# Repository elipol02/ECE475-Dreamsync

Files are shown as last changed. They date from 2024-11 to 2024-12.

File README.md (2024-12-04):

# Dreamsync

## Project Overview
Our product Dreamsync is designed to enhance health monitoring by integrating sensors that track various metrics related to sleep quality and environmental conditions. Data collected from the sensors are transmitted to a companion mobile application via Bluetooth for analysis and visualization. This will make it easier for our users to track their sleeping patterns.

### Features
- **Sleep Movement Monitoring**: Tracks body movements during sleep using an MPU6050 accelerometer and gyroscope.
- **Heart Rate Monitoring**: Continuously monitors heart rate using a photoplethysmography (PPG) sensor.
- **Environmental Light Exposure**: Measures light levels in the sleep environment using light sensors.
- **Ambient Temperature Monitoring**: Tracks the ambient temperature using a DS18B20 temperature sensor.
- **Battery Monitoring**: Measures battery voltage, percentage, and charging status.
- **Bluetooth Connectivity**: Transmits real-time sensor data to a companion app via BLE (Bluetooth Low Energy).

---

## Components and Dependencies

### Hardware Components
- **MPU6050**: Accelerometer and gyroscope for motion tracking.
- **DS18B20**: Temperature sensor.
- **PPG Sensor**: For heart rate monitoring.
- **Light Sensors**: Measures light levels (connected to analog pins A0 and A1).
- **nRF52840 Feather**: For Bluetooth communication.
- **LED**: Visual feedback for heart rate peaks.

### Software Libraries
- **Wire**: I2C communication with MPU6050.
- **OneWire**: Communication protocol for DS18B20.
- **DallasTemperature**: Interface for DS18B20 temperature sensor.
- **Adafruit Bluefruit**: Bluetooth communication.
- **Adafruit LittleFS**: Internal file system for configuration storage.

---

## Setup Instructions

### Hardware Setup
1. Connect the **MPU6050** to the I2C pins (SDA, SCL).
2. Attach the **DS18B20** sensor to `TEMP_SENSOR_PIN` (A2).
3. Connect **PPG Sensor** to `HEART_RATE_PIN` (A3).
4. Connect light sensors to `LIGHT_SENSOR_1` (A0) and `LIGHT_SENSOR_2` (A1).
5. Connect the LED to `LED_PIN` (3).

### Software Setup
1. You'll need to install the libraries we listed above.
2. Upload the firmware code provided to your nRF52840 development board via Arduino IDE.

### Mobile Application
1. Ensure the Bluetooth is enabled on your mobile device.
2. Pair with the "SleepMask" device via BLE.
3. Use the companion app to visualize and analyze the collected data.

---

## Code Highlights

### Key Functions
- **`initializeMPU6050()`**: Initializes the MPU6050 for motion tracking.
- **`readLightAndTemp()`**: Reads ambient light and temperature values.
- **`readHeartRateSensor()`**: Reads and processes heart rate data.
- **`calculateBPM()`**: Calculates beats per minute (BPM) based on PPG data.
- **`sendEnvironmentalData()`**: Sends light and temperature data over BLE.
- **`checkBattery()`**: Monitors battery voltage and percentage.
- **`startAdv()`**: Configures and starts BLE advertising.

### BLE Services
- **Device Information Service**: Provides metadata about the device.
- **UART Service**: Transmits sensor data to the mobile app.
- **Battery Service**: Sends battery status updates.

---

## Sensor Data Format

The sensor data is transmitted to the companion app in the following format:
1. **Environmental Data**: `E,light1,light2,temperature`
2. **Heart Rate Data**: `H,heartRate`
3. **Motion Data**: `M,accelX,accelY,accelZ,gyroX,gyroY,gyroZ,pitch,roll,motionIntensity`
4. **Battery Data**: `B,batteryVoltage,batteryPercent,isCharging`

---

## Contributors

Chukwuemeka Mordi, Chu-en Chang, Elijah Pollack, Kinner Parikh

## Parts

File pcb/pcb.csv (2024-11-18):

Source: | C:\Users\Eli\Documents\GitHub\ece475group7\pcb\pcb.kicad_sch
Date: | 11/16/2024 10:39
Tool: | Eeschema 7.0.10
Generator: | C:\Program Files\KiCad\7.0\bin\scripting\plugins/bom_csv_grouped_by_value_with_fp.py
Component Count: | 109
Ref | Qnty | Value | Cmp name | Footprint | Description | Vendor | DNP
C1 | 1 | 0.01uF | GRM155R71C103KA01D | Library:CAPC2012X95N
C2, C3, C4, C15, C16, C17, C18, C20, C21, C24, C25, C27, C28, C31, C34, C36, C38, C40 | 18 | 0.1uF | CL05B104KP5NNNC | Library:CAPC2012X88N
C5, C6 | 2 | 22pF | CAP_CERAMIC0603_NO | Library:CAPC220145_88N_KEM
C7, C8, C12, C13, C14 | 5 | 10uF | CAP_CERAMIC0805-NOOUTLINE | Library:CAPC2012X88N
C9, C10, C11 | 3 | 0.1uF | CAP_CERAMIC0603_NO | Library:CAPC2012X88N
C19, C26, C35, C37 | 4 | 10uF | CL21A106KOQNNNG | Library:CAPC2012X88N
C22, C29, C32, C39, C41 | 5 | 2.2nF | Capacitor | Library:CAP_CL21_SAM
C23, C30, C33, C42 | 4 | 1nF | Capacitor | Library:CAP_0805J_AVX
D1 | 1 | RED | LED0805_NOOUTLINE | Library:WL-SMCW_0805
D2 | 1 | MBR120 | DIODE-SCHOTTKYSOD-123 | Library:SDO_SOD-123FL498_OSI
D3 | 1 | ORANGE | LED0805_NOOUTLINE | Library:WL-SMCW_0805
D4 | 1 | BLUE | LED0805_NOOUTLINE | Library:WL-SMCW_0805
D5 | 1 | 2659 | 2659 | Library:2659
IC1 | 1 | GD25Q16 | SPIFLASH_8PINUX | Library:SOIC127P600X175-8N
J1 | 1 | 10118194-0001LF | 10118194-0001LF | Library:AMPHENOL_10118194-0001LF
J2 | 1 | 533980271 | 533980271 | Library:MOLEX_0533980271
MDBT1 | 1 | MDBT50 | MDBT50 | Library:MDBT50Q-U
Q3 | 1 | DMG2305 | MOSFET-P | Library:SOT91P240X110-3N_DMG2305UX-7
R1, R2, R3, R14, R19, R32 | 6 | 22 | CRCW251220R0FKEG | Library:RESC2012X60N
R4, R5, R8, R11, R15, R20, R22, R25, R26, R27, R33 | 11 | 4.7K | Resistor | Library:RESC2012X60N
R6, R9, R10 | 3 | 1K | RESISTOR_0603_NOOUT | Library:RESC2012X60N
R7, R24, R36, R37, R38 | 5 | 100K | Resistor | Library:RESC2012X60N
R12, R13, R18, R31 | 4 | 2.2K | Resistor | Library:RESC2012X60N
R16, R17, R21, R28, R29, R30, R34, R35 | 8 | 3.74K | Resistor | Library:RESC2012X60N
R23 | 1 | 30K | ERA2AEB303X | Library:RESC2012X65N
SW1, SW2 | 2 | KMR223G LFG | KMR223G_LFG | Library:KMR2_G_CNK
U1 | 1 | MPU-6050 | MPU-6050 | Sensor_Motion:InvenSense_QFN-24_4x4mm_P0.5mm | InvenSense 6-Axis Motion Sensor, Gyroscope, Accelerometer, I2C
U2 | 1 | DS18B20 | DS18B20 | Package_TO_SOT_THT:TO-92_Inline | Programmable Resolution 1-Wire Digital Thermometer TO-92
U4, U5, U10, U12 | 4 | INA333xxDGK | INA333xxDGK | Library:SOP65P490X110-8N | Zero Drift, Micropower Instrumentation Amplifier G = 1 + 100kOhm/Rg, VSSOP-8
U6 | 1 | CS5523-ASZ | CS5523-ASZ | Library:CIR-SSOP-24
U7 | 1 | AP2112(3.3V) | VREG_SOT23-5 | Library:SOT_RG1_DIO
U8 | 1 | MCP73831T-2ACI/OT | MCP73831/2 | Library:SOT-23-5_MC_MCH
U9, U11, U13, U15 | 4 | LM358DT | LM358DT | Library:SOIC127P600X175-8N
U20 | 1 | MCP6001-OT | MCP6001-OT | Package_TO_SOT_SMD:SOT-23-5 | 1MHz, Low-Power Op Amp, SOT-23-5
X1 | 1 | 2x5 0.05" | JTAG-CORTEXBOXPOSTS | Library:2X05_1.27MM_BOX_POSTS
Y1 | 1 | 32.768 | XTAL-3.2X1.5 | Library:XTAL_SC32S-7PF20PPM_EPS
 | 108

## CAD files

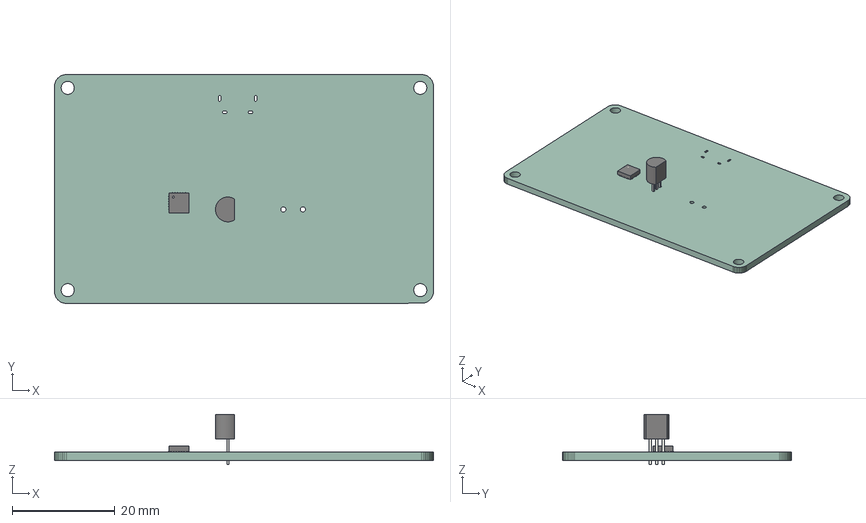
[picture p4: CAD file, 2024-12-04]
pcb/pcb.step
73.7 x 44.5 x 9.80 mm
TO-92_Inline_Narrow
QFN_24_1EP_4x4mm_P05mm_EP27x26mm
_autosave-pcb PCB

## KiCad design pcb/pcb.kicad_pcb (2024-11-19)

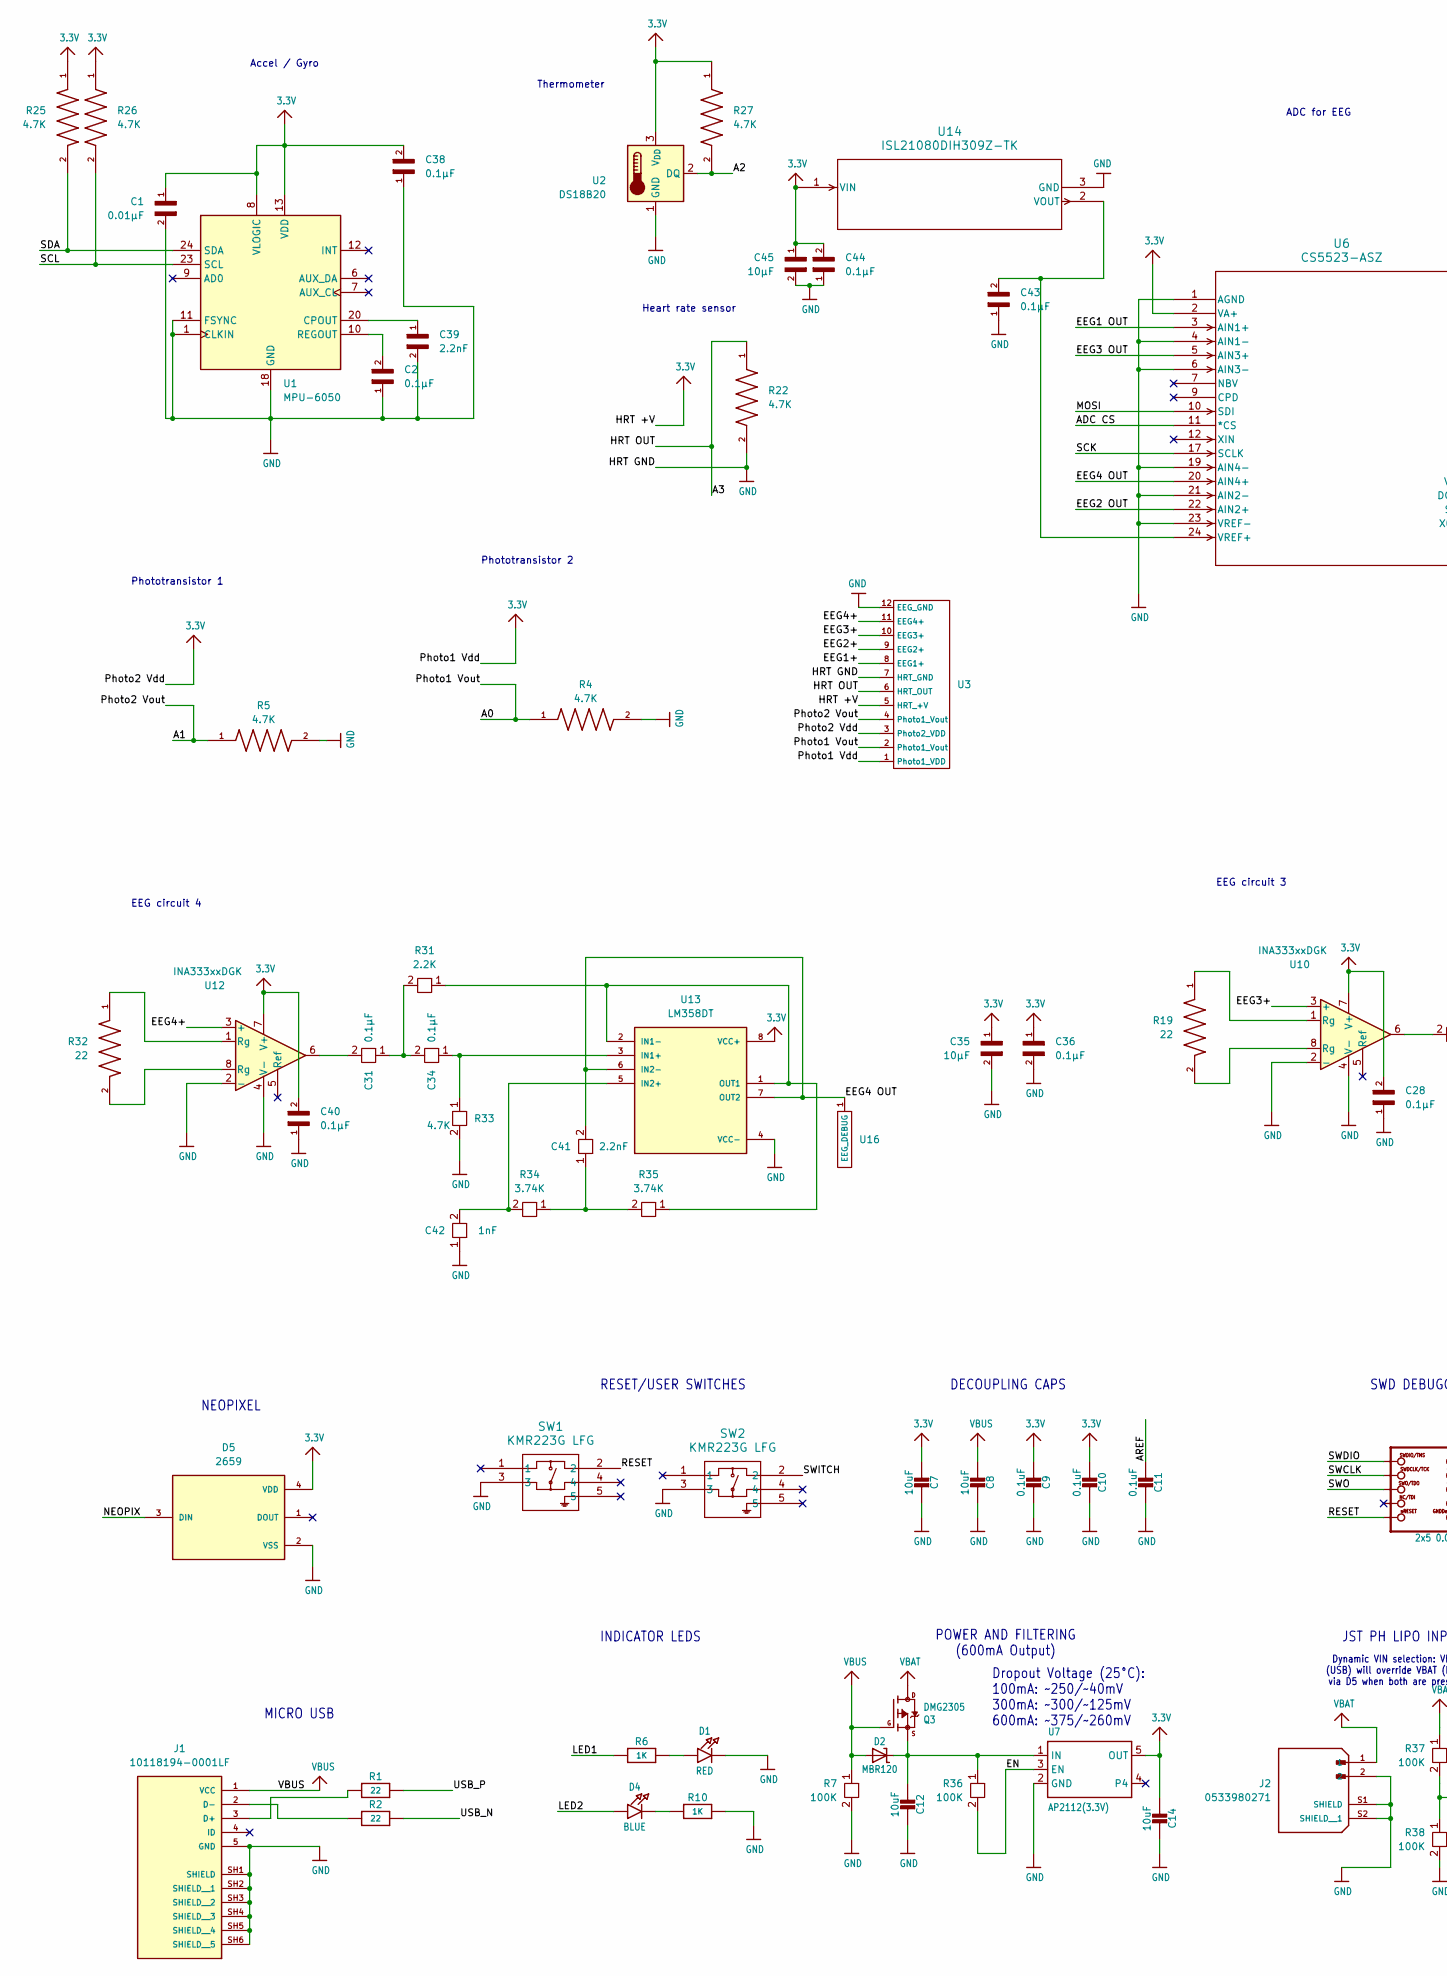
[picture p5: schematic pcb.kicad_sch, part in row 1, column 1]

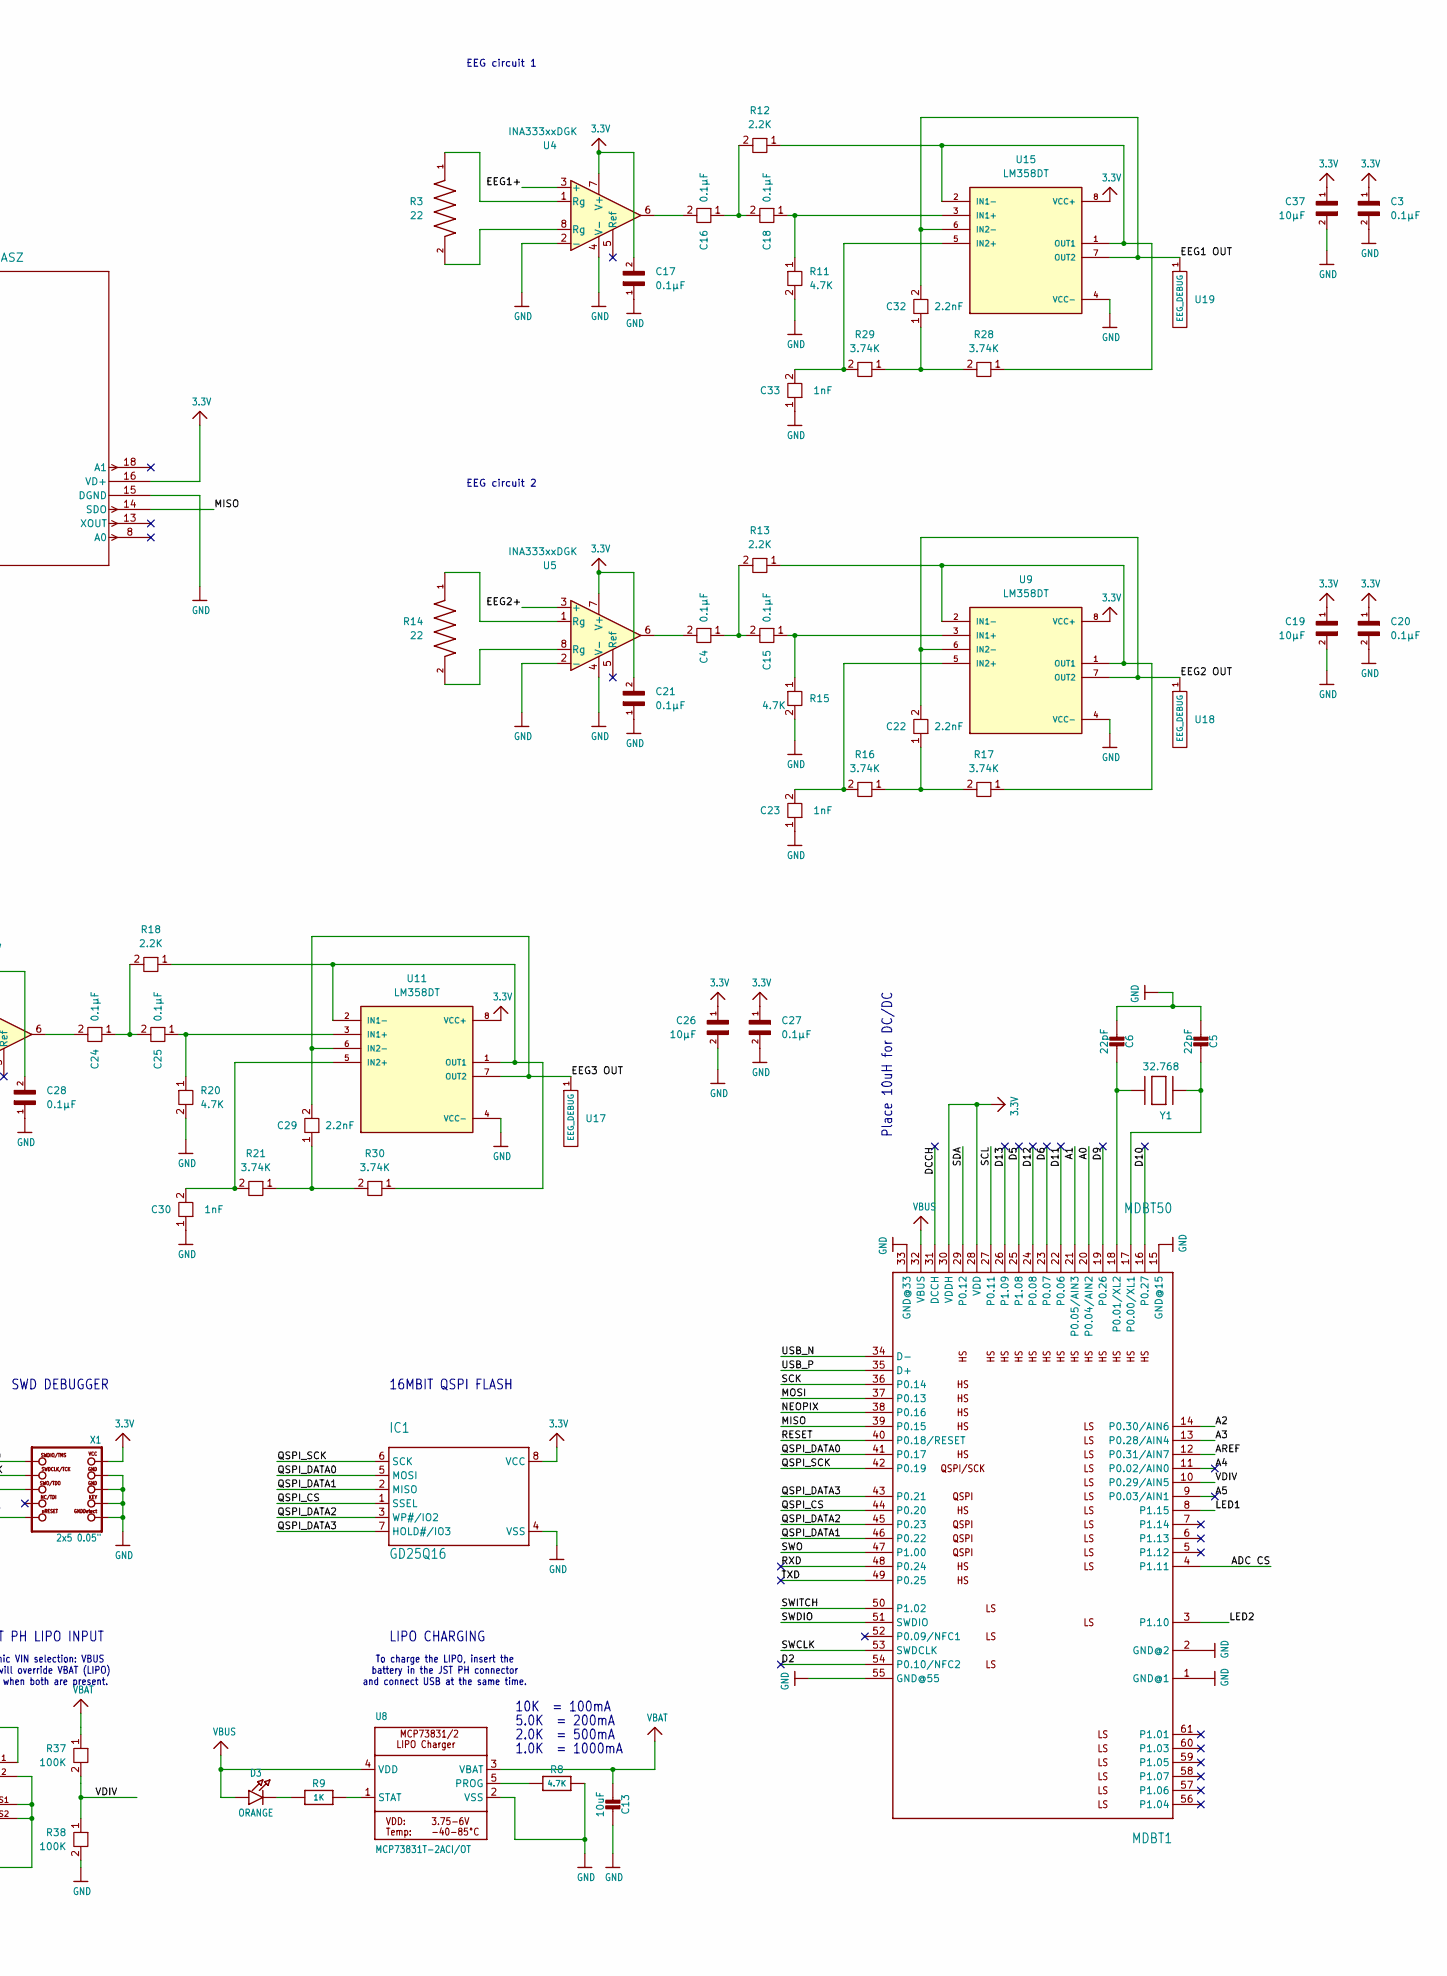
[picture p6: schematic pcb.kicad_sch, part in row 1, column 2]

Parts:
C1: 0.01μF; CAPC2012X95N
C2, C3, C4, C15, C16, C17, C18, C20, C21, C24, C25, C27, C28, C31, C34, C36, C38, C40, C43, C44: 0.1μF; CAPC2012X88N
C5, C6: 22pF; CAPC220145_88N_KEM
C7, C8, C12, C13, C14: 10uF; CAPC2012X88N
C9, C10, C11: 0.1uF; CAPC2012X88N
C19, C26, C35, C37, C45: 10μF; CAPC2012X88N
C22, C29, C32, C39, C41: 2.2nF; CAP_CL21_SAM
C23, C30, C33, C42: 1nF; CAP_0805J_AVX
D1: RED; WL-SMCW_0805
D2: MBR120; SDO_SOD-123FL498_OSI
D3: ORANGE; WL-SMCW_0805
D4: BLUE; WL-SMCW_0805
D5: 2659; PARTREV 01
IC1: GD25Q16; SOIC127P600X175-8N
J1: 10118194-0001LF; AMPHENOL_10118194-0001LF; PARTREV D
J2: 0533980271; MOLEX_0533980271; PARTREV A
MDBT1: MDBT50; MDBT50Q-U
Q3: DMG2305; SOT91P240X110-3N_DMG2305UX-7
R1, R2, R3, R14, R19, R32: 22; RESC2012X60N
R4, R5, R22, R25, R26, R27: 4.7K; RESC2012X60N; DigiKey_Part_Number 311-4.7KJRTR-ND
R6, R9, R10: 1K; RESC2012X60N
R7, R36, R37, R38: 100K; RESC2012X60N
R8, R11, R15, R20, R33: 4.7K; RESC2012X60N
R12, R13, R18, R31: 2.2K; RESC2012X60N
R16, R17, R21, R28, R29, R30, R34, R35: 3.74K; RESC2012X60N
SW1, SW2: KMR223G LFG; KMR2_G_CNK
U1: MPU-6050; InvenSense_QFN-24_4x4mm_P0.5mm
U2: DS18B20; TO-92_Inline
U3: Sensors
U4, U5, U10, U12: INA333xxDGK; SOP65P490X110-8N
U6: CS5523-ASZ; CIR-SSOP-24
U7: AP2112(3.3V); SOT_RG1_DIO
U8: MCP73831T-2ACI/OT; SOT-23-5_MC_MCH
U9, U11, U13, U15: LM358DT; SOIC127P600X175-8N
U14: ISL21080DIH309Z-TK; P3_064_INR
U16, U17, U18, U19: EEG_DEBUG
X1: 2x5 0.05"; 2X05_1.27MM_BOX_POSTS
Y1: 32.768; XTAL_SC32S-7PF20PPM_EPS

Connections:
3.3V: C1.1, C3.1, C7.2, C9.2, C10.2, C14.2, C17.2, C19.1, C20.1, C21.2, C26.1, C27.1, C28.2, C35.1, C36.1, C37.1, C38.2, C40.2, C44.2, C45.1, D5.4 (VDD), IC1.8 (VCC), MDBT1.28 (VDD), MDBT1.30 (VDDH), R25.1, R26.1, R27.1, U1.8 (VLOGIC), U1.13 (VDD), U2.3 (V_{DD}), U3.1 (Photo1_VDD), U3.3 (Photo2_VDD), U3.5 (HRT_+V), U4.7 (V+), U5.7 (V+), U6.2 (VA+), U6.16 (VD+), U7.5 (OUT), U9.8 (VCC+), U10.7 (V+), U11.8 (VCC+), U12.7 (V+), U13.8 (VCC+), U14.1 (VIN), U15.8 (VCC+), X1.1 (VCC)
/A0: MDBT1.20 (P0.04/AIN2), R4.1, U3.2 (Photo1_Vout)
/A1: MDBT1.21 (P0.05/AIN3), R5.1, U3.4 (Photo1_Vout)
/A2: MDBT1.14 (P0.30/AIN6), R27.2, U2.2 (DQ)
/A3: MDBT1.13 (P0.28/AIN4), R22.1, U3.6 (HRT_OUT)
/A4: MDBT1.11 (P0.02/AIN0)
/A5: MDBT1.9 (P0.03/AIN1)
/ADC CS: MDBT1.4 (P1.11), U6.11 (*CS)
/AREF: C11.2, MDBT1.12 (P0.31/AIN7)
/D2: MDBT1.54 (P0.10/NFC2)
/D5: MDBT1.25 (P1.08)
/D6: MDBT1.23 (P0.07)
/D9: MDBT1.19 (P0.26)
/D10: MDBT1.16 (P0.27)
/D11: MDBT1.22 (P0.06)
/D12: MDBT1.24 (P0.08)
/D13: MDBT1.26 (P1.09)
/DCCH: MDBT1.31 (DCCH)
/EEG1 OUT: C32.2, U6.3 (AIN1+), U15.6 (IN2-), U15.7 (OUT2), U19.1 (EEG_DEBUG)
/EEG1+: U3.8 (EEG1+), U4.3 (+)
/EEG2 OUT: C22.2, U6.22 (AIN2+), U9.6 (IN2-), U9.7 (OUT2), U18.1 (EEG_DEBUG)
/EEG2+: U3.9 (EEG2+), U5.3 (+)
/EEG3 OUT: C29.2, U6.5 (AIN3+), U11.6 (IN2-), U11.7 (OUT2), U17.1 (EEG_DEBUG)
/EEG3+: U3.10 (EEG3+), U10.3 (+)
/EEG4 OUT: C41.2, U6.20 (AIN4+), U13.6 (IN2-), U13.7 (OUT2), U16.1 (EEG_DEBUG)
/EEG4+: U3.11 (EEG4+), U12.3 (+)
/EN: R36.2, U7.3 (EN)
/LED1: MDBT1.8 (P1.15), R6.1
/LED2: D4.A, MDBT1.3 (P1.10)
/MISO: MDBT1.39 (P0.15), U6.14 (SDO)
/MOSI: MDBT1.37 (P0.13), U6.10 (SDI)
/NEOPIX: D5.3 (DIN), MDBT1.38 (P0.16)
/QSPI_CS: IC1.1 (SSEL), MDBT1.44 (P0.20)
/QSPI_DATA0: IC1.5 (MOSI), MDBT1.41 (P0.17)
/QSPI_DATA1: IC1.2 (MISO), MDBT1.46 (P0.22)
/QSPI_DATA2: IC1.3 (WP#/IO2), MDBT1.45 (P0.23)
/QSPI_DATA3: IC1.7 (HOLD#/IO3), MDBT1.43 (P0.21)
/QSPI_SCK: IC1.6 (SCK), MDBT1.42 (P0.19)
/RESET: MDBT1.40 (P0.18/RESET), SW1.2, X1.10 (NRESET)
/RXD: MDBT1.48 (P0.24)
/SCK: MDBT1.36 (P0.14), U6.17 (SCLK)
/SCL: MDBT1.27 (P0.11), R26.2, U1.23 (SCL)
/SDA: MDBT1.29 (P0.12), R25.2, U1.24 (SDA)
/SWCLK: MDBT1.53 (SWDCLK), X1.4 (SWDCLK)
/SWDIO: MDBT1.51 (SWDIO), X1.2 (SWDIO)
/SWITCH: MDBT1.50 (P1.02), SW2.2
/SWO: MDBT1.47 (P1.00), X1.6 (SWO)
/TXD: MDBT1.49 (P0.25)
/USB_N: MDBT1.34 (D-), R2.2
/USB_P: MDBT1.35 (D+), R1.2
/VDIV: MDBT1.10 (P0.29/AIN5), R37.2, R38.1
GND: C1.2, C2.1, C3.2, C5.2, C6.2, C7.1, C8.1, C9.1, C10.1, C11.1, C12.1, C13.1, C14.1, C17.1, C19.2, C20.2, C21.1, C23.1, C26.2, C27.2, C28.1, C30.1, C33.1, C35.2, C36.2, C37.2, C38.1, C39.2, C40.1, C42.1, C43.1, C44.1, C45.2, D1.C, D5.2 (VSS), IC1.4 (VSS), J1.5 (GND), J1.SH1 (SHIELD), J1.SH2 (SHIELD__1), J1.SH3 (SHIELD__2), J1.SH4 (SHIELD__3), J1.SH5 (SHIELD__4), J1.SH6 (SHIELD__5), J2.2, J2.S1 (SHIELD), J2.S2 (SHIELD__1), MDBT1.1 (GND@1), MDBT1.2 (GND@2), MDBT1.15 (GND@15), MDBT1.33 (GND@33), MDBT1.55 (GND@55), R4.2, R5.2, R7.2, R8.2, R10.2, R11.2, R15.2, R20.2, R22.2, R33.2, R38.2, SW1.3, SW2.3, U1.1 (CLKIN), U1.11 (FSYNC), U1.18 (GND), U2.1 (GND), U3.7 (HRT_GND), U3.12 (EEG_GND), U4.2 (-), U4.4 (V-), U5.2 (-), U5.4 (V-), U6.1 (AGND), U6.4 (AIN1-), U6.6 (AIN3-), U6.15 (DGND), U6.19 (AIN4-), U6.21 (AIN2-), U6.23 (VREF-), U7.2 (GND), U8.2 (VSS), U9.4 (VCC-), U10.2 (-), U10.4 (V-), U11.4 (VCC-), U12.2 (-), U12.4 (V-), U13.4 (VCC-), U14.3 (GND), U15.4 (VCC-), X1.3 (GND@1), X1.5 (GND@2), X1.7 (KEY), X1.9 (GNDDETECT)
unnamed: C4.2, U5.6
unnamed: C4.1, C15.2, R13.2
unnamed: C16.1, C18.2, R12.2
unnamed: C16.2, U4.6
unnamed: C22.1, R16.1, R17.2
unnamed: C24.1, C25.2, R18.2
unnamed: C24.2, U10.6
unnamed: C29.1, R21.1, R30.2
unnamed: C31.1, C34.2, R31.2
unnamed: C31.2, U12.6
unnamed: C32.1, R28.2, R29.1
unnamed: C41.1, R34.1, R35.2
unnamed: D1.A, R6.2
unnamed: D3.C, R9.1
unnamed: D4.C, R10.1
unnamed: J1.3 (D+), R1.1
unnamed: J1.2 (D-), R2.1
unnamed: C5.1, MDBT1.17 (P0.00/XL1), Y1.1
unnamed: C6.1, MDBT1.18 (P0.01/XL2), Y1.2
unnamed: C12.2, D2.C, Q3.2 (S), R36.1, U7.1 (IN)
unnamed: R3.1, U4.1 (Rg)
unnamed: R3.2, U4.8 (Rg)
unnamed: R14.1, U5.1 (Rg)
unnamed: R14.2, U5.8 (Rg)
unnamed: R19.1, U10.1 (Rg)
unnamed: R19.2, U10.8 (Rg)
unnamed: R32.1, U12.1 (Rg)
unnamed: R32.2, U12.8 (Rg)
unnamed: C39.1, U1.20 (CPOUT)
unnamed: C2.2, U1.10 (REGOUT)
unnamed: R8.1, U8.5 (PROG)
unnamed: R9.2, U8.1 (STAT)
unnamed: C15.1, R15.1, U9.3 (IN1+)
unnamed: R13.1, R17.1, U9.1 (OUT1), U9.2 (IN1-)
unnamed: C23.2, R16.2, U9.5 (IN2+)
unnamed: C25.1, R20.1, U11.3 (IN1+)
unnamed: R18.1, R30.1, U11.1 (OUT1), U11.2 (IN1-)
unnamed: C30.2, R21.2, U11.5 (IN2+)
unnamed: C34.1, R33.1, U13.3 (IN1+)
unnamed: R31.1, R35.1, U13.1 (OUT1), U13.2 (IN1-)
unnamed: C42.2, R34.2, U13.5 (IN2+)
unnamed: C43.2, U6.24 (VREF+), U14.2 (VOUT)
unnamed: C18.1, R11.1, U15.3 (IN1+)
unnamed: R12.1, R28.1, U15.1 (OUT1), U15.2 (IN1-)
unnamed: C33.2, R29.2, U15.5 (IN2+)
VBAT: C13.2, J2.1, Q3.3 (D), R37.1, U8.3 (VBAT)
VBUS: C8.2, D2.A, D3.A, J1.1 (VCC), MDBT1.32 (VBUS), Q3.1 (G), R7.1, U8.4 (VDD)

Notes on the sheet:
EEG circuit 3
SWD DEBUGGER
EEG circuit 2
LIPO CHARGING
JST PH LIPO INPUT
To charge the LIPO, insert the battery in the JST PH connector and connect USB at the same time.
Phototransistor 1
Place 10uH for DC/DC
DECOUPLING CAPS
10K = 100mA
2.0K = 500mA
POWER AND FILTERING (600mA Output)
16MBIT QSPI FLASH
Thermometer
Phototransistor 2
Heart rate sensor
RESET/USER SWITCHES
1.0K = 1000mA
Dropout Voltage (25°C): 100mA: ~250/~40mV 300mA: ~300/~125mV 600mA: ~375/~260mV
EEG circuit 4
Dynamic VIN selection: VBUS (USB) will override VBAT (LIPO) via D5 when both are present.
NEOPIXEL
ADC for EEG
Accel / Gyro
INDICATOR LEDS
5.0K = 200mA
EEG circuit 1
MICRO USB

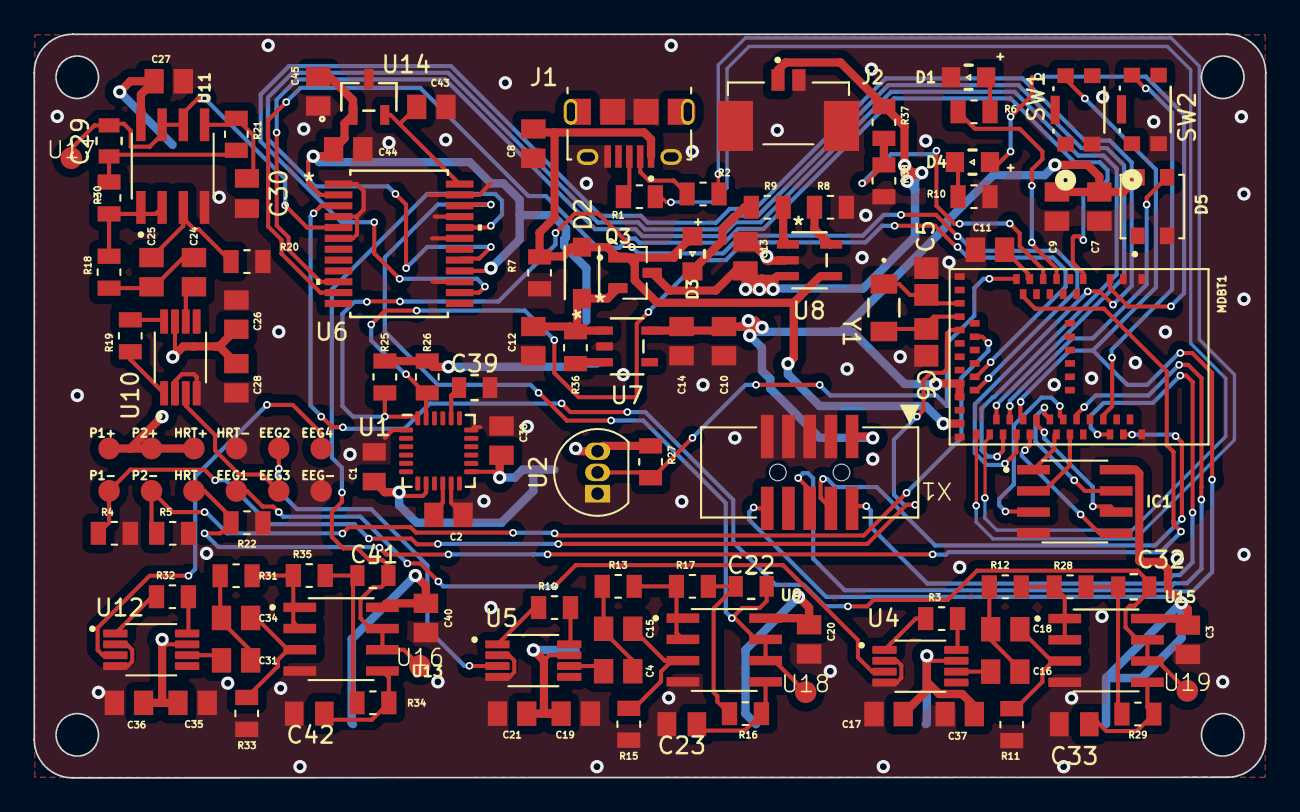
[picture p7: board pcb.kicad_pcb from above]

Board: 2 copper layers, 73.7 x 44.5 mm, 114 parts (0 on the bottom side), 86 nets.

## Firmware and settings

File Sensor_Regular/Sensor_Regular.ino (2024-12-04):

#include <Wire.h>
#include <OneWire.h>
#include <DallasTemperature.h>
#include <bluefruit.h>
#include <Adafruit_LittleFS.h>
#include <InternalFileSystem.h>

#define LIGHT_SENSOR_1 A0
#define LIGHT_SENSOR_2 A1
#define TEMP_SENSOR_PIN A2    // DS18B20 connected to this pin
#define HEART_RATE_PIN A3
#define LED_PIN 3  // pin for LED

// MPU6050 Constants
#define MPU6050_ADDR         0x68   // default I2C address 
#define MPU6050_PWR_MGMT_1   0x6B   // Power Management 1 register
#define MPU6050_GYRO_CONFIG  0x1B   // Gyroscope Configuration register
#define MPU6050_ACCEL_CONFIG 0x1C   // Accelerometer Configuration register
#define MPU6050_ACCEL_XOUT_H 0x3B   // first data register 

// bluetooth setup using hardware UART for nRF52840
//#define BLE_SERIAL Serial1

// BLE services 
BLEDfu  bledfu;  // OTA DFU service
BLEDis  bledis;  // device information
BLEUart bleuart; // uart over ble
BLEBas  blebas;  // battery

// DS18B20 OneWire bus
OneWire oneWire(TEMP_SENSOR_PIN);
DallasTemperature tempSensor(&oneWire);

// Timing intervals (in milliseconds)
const unsigned long LIGHT_TEMP_INTERVAL = 60000;  // 1 minute for light and temperature reading
const unsigned long HEART_RATE_INTERVAL = 100;   // 100 milliseconds for heart rate checking
const unsigned long HEART_RATE_MEASUREMENT_TIME = 15000;  // 15 seconds for BPM measurement
const unsigned long ENVIRONMENTAL_INTERVAL = 60000;  // 1 minute for environmental data output
const unsigned long MPU6050_INTERVAL = 100;  // 100ms (10Hz)
const unsigned long BATTERY_INTERVAL = 1000;  // 1 second

unsigned long lastLightTempReading = 0;
unsigned long lastHeartRateReading = 0;
unsigned long lastEnvironmentalReading = 0;  // track the last environmental data reading
unsigned long measurementStartTime = 0;  // track start time for heart rate measurement

// i just followed suit with MPU and batter
unsigned long lastMPUReading = 0;       
unsigned long lastBatteryReading = 0;

// Buffer for heart rate data
const int SAMPLES = 100;
int ppgBuffer[SAMPLES];
int bufferIndex = 0;
int peakCount = 0;
unsigned long lastPeakTime = 0;

// sensor data struct that contains our MPU6050 data
struct MPU6050Data {
    // accel raw values (16-bit)
    int16_t accelX;
    int16_t accelY;
    int16_t accelZ;
    
    // gyro raw values (16-bit)
    int16_t gyroX;
    int16_t gyroY;
    int16_t gyroZ;
    
    // temperature
    // this was in teh example code from docs but not sure if we need
    float temperature;
    
    // calculated values
    float pitch;
    float roll;
    float motionIntensity;
} mpuData;

struct SensorData {
    int light1;
    int light2;
    float temperature;
    int heartRate;
    MPU6050Data mpu;
    float batteryVoltage;
    int batteryPercent;
    bool isCharging;
} sensorData;

bool mpuInitialized = false;

// bluetooth helper
void startAdv(void)
{
    // Advertising packet
    Bluefruit.Advertising.addFlags(BLE_GAP_ADV_FLAGS_LE_ONLY_GENERAL_DISC_MODE);
    Bluefruit.Advertising.addTxPower();
    Bluefruit.Advertising.addService(bleuart);
    Bluefruit.ScanResponse.addName();
    
    Bluefruit.Advertising.restartOnDisconnect(true);
    Bluefruit.Advertising.setInterval(32, 244);    // in unit of 0.625 ms
    Bluefruit.Advertising.setFastTimeout(30);      // number of seconds in fast mode
    Bluefruit.Advertising.start(0);                // 0 = Don't stop advertising
}

// bluetooth helper
void connect_callback(uint16_t conn_handle)
{
    BLEConnection* connection = Bluefruit.Connection(conn_handle);
    char central_name[32] = { 0 };
    connection->getPeerName(central_name, sizeof(central_name));
    Serial.print("Connected to ");
    Serial.println(central_name);
}

// bluetooth helper
void disconnect_callback(uint16_t conn_handle, uint8_t reason)
{
    Serial.print("Disconnected, reason = 0x");
    Serial.println(reason, HEX);
}

void setup() {
    // intialize serial communication
    Serial.begin(115200);
    // while (!Serial) delay(10);

    Serial.println("Sleep Mask BLE Setup");

    // Initialize Bluefruit
    Bluefruit.begin();
    Bluefruit.setTxPower(4);    // Check bluefruit.h for supported values
    Bluefruit.setName("SleepMask");
    
    // Callbacks for Peripheral
    Bluefruit.Periph.setConnectCallback(connect_callback);
    Bluefruit.Periph.setDisconnectCallback(disconnect_callback);

    // Configure and Start Services
    bledfu.begin();             // OTA DFU service
    
    bledis.setManufacturer("Your Name");
    bledis.setModel("Sleep Mask v1.0");
    bledis.begin();
    
    bleuart.begin();           // Configure and Start BLE Uart service
    blebas.begin();            // Start BLE Battery service
    
    // Start advertising
    startAdv();


    // initiailize I2C
    Wire.begin();


    // initialize MPU6050
    mpuInitialized = initializeMPU6050();
    if (!mpuInitialized) {
        Serial.println("Failed to initialize MPU6050!");
    } else {
        Serial.println("MPU6050 initialized successfully");
    }

    // initialize temperature sensor
    tempSensor.begin();

    // Set pin modes
    pinMode(LIGHT_SENSOR_1, INPUT);
    pinMode(LIGHT_SENSOR_2, INPUT);
    pinMode(HEART_RATE_PIN, INPUT);
    pinMode(LED_PIN, OUTPUT);  // set LED pin as output

    Serial.println("Setup complete");
}

// Most of the initializeMPU6050() is just pulled from tutorial and examples i saw online
bool initializeMPU6050() {
    // check if MPU6050 is responding
    Wire.beginTransmission(MPU6050_ADDR);
    if (Wire.endTransmission() != 0) {
        Serial.println("MPU6050 not found!");
        return false;
    }
    
    // wake up the MPU6050
    Wire.beginTransmission(MPU6050_ADDR);
    Wire.write(MPU6050_PWR_MGMT_1);
    Wire.write(0x00);  // Clear sleep mode bit
    Wire.endTransmission(true);
    
    delay(100); // Wait for wake-up
    
    // configure accelerometer (+/- 2g)
    Wire.beginTransmission(MPU6050_ADDR);
    Wire.write(MPU6050_ACCEL_CONFIG);
    Wire.write(0x00);  // 0x00 = +/- 2g
    Wire.endTransmission(true);
    
    // configuring gyroscope (+/- 250 deg/s)
    Wire.beginTransmission(MPU6050_ADDR);
    Wire.write(MPU6050_GYRO_CONFIG);
    Wire.write(0x00);  // 0x00 = +/- 250 degrees/second
    Wire.endTransmission(true);

    return true;
}

void loop() {
    unsigned long currentTime = millis();
    static bool lastConnected = false;
    bool currentConnected = Bluefruit.connected();
    
    // using this to test the connection status
    if (currentConnected != lastConnected) {
        if (currentConnected) {
            Serial.println("BLE Connected!");
        } else {
            Serial.println("BLE Disconnected!");
        }
        lastConnected = currentConnected;
    }

    // check light and temperature
    if (currentTime - lastLightTempReading >= LIGHT_TEMP_INTERVAL) {
        readLightAndTemp();
        lastLightTempReading = currentTime;
    }

    // heart rate measurement
    if (currentTime - measurementStartTime >= HEART_RATE_MEASUREMENT_TIME) {
        sensorData.heartRate = calculateBPM();
        sendHeartRateData();
        peakCount = 0;
        measurementStartTime = currentTime;
    }

    // continous heart rate monitoring
    if (currentTime - measurementStartTime < HEART_RATE_MEASUREMENT_TIME) {
        readHeartRateSensor();
    }

    // MPU6050 reading
    if (currentTime - lastMPUReading >= MPU6050_INTERVAL && mpuInitialized) {
        readMPU6050();
        sendMotionData();
        lastMPUReading = currentTime;
    }

    // battery check
    if (currentTime - lastBatteryReading >= BATTERY_INTERVAL) {
        checkBattery();
        sendBatteryData();
        lastBatteryReading = currentTime;
    }

    // environmental data
    if (currentTime - lastEnvironmentalReading >= ENVIRONMENTAL_INTERVAL) {
        sendEnvironmentalData();
        lastEnvironmentalReading = currentTime;
    }

    delay(10);  // small delay to prevent overwhelming the system
}

void readLightAndTemp() {
    sensorData.light1 = analogRead(LIGHT_SENSOR_1);
    sensorData.light2 = analogRead(LIGHT_SENSOR_2);
    tempSensor.requestTemperatures();
    sensorData.temperature = tempSensor.getTempCByIndex(0);
}

void readHeartRateSensor() {
    int rawValue = analogRead(HEART_RATE_PIN);
    ppgBuffer[bufferIndex] = rawValue;
    bufferIndex = (bufferIndex + 1) % SAMPLES;

    int sum = 0;
    for (int i = 0; i < SAMPLES; i++) {
        sum += ppgBuffer[i];
    }
    int filteredValue = sum / SAMPLES;

    int threshold = 730;
    if (rawValue > threshold && (millis() - lastPeakTime) > 300) {
        peakCount++;
        lastPeakTime = millis();
        digitalWrite(LED_PIN, HIGH);
        delay(100);
        digitalWrite(LED_PIN, LOW);
    }
}

void readMPU6050() {
    Wire.beginTransmission(MPU6050_ADDR);
    Wire.write(MPU6050_ACCEL_XOUT_H);
    Wire.endTransmission(false);
    Wire.requestFrom(MPU6050_ADDR, 14, true);

    if (Wire.available() >= 14) {
        sensorData.mpu.accelX = Wire.read() << 8 | Wire.read();
        sensorData.mpu.accelY = Wire.read() << 8 | Wire.read();
        sensorData.mpu.accelZ = Wire.read() << 8 | Wire.read();
        
        int16_t tempRaw = Wire.read() << 8 | Wire.read();
        sensorData.mpu.temperature = tempRaw / 340.0 + 36.53;
        
        sensorData.mpu.gyroX = Wire.read() << 8 | Wire.read();
        sensorData.mpu.gyroY = Wire.read() << 8 | Wire.read();
        sensorData.mpu.gyroZ = Wire.read() << 8 | Wire.read();
        
        calculateAngles();
        
        sensorData.mpu.motionIntensity = sqrt(
            pow(sensorData.mpu.accelX / 16384.0, 2) +
            pow(sensorData.mpu.accelY / 16384.0, 2) +
            pow(sensorData.mpu.accelZ / 16384.0, 2)
        );
    }
}

void calculateAngles() {
    float x = sensorData.mpu.accelX / 16384.0;
    float y = sensorData.mpu.accelY / 16384.0;
    float z = sensorData.mpu.accelZ / 16384.0;
    
    sensorData.mpu.pitch = atan2(x, sqrt(y * y + z * z));
    sensorData.mpu.roll = atan2(y, sqrt(x * x + z * z));
    
    sensorData.mpu.pitch *= 180.0 / M_PI;
    sensorData.mpu.roll *= 180.0 / M_PI;
}

int calculateBPM() {
    int bpm = peakCount * 4;
    Serial.print("Heartbeats in 15s: ");
    Serial.println(peakCount);
    Serial.print("Calculated BPM: ");
    Serial.println(bpm);
    return bpm;
}

void sendEnvironmentalData() {
    String data = "E," + String(sensorData.light1) + "," + 
                 String(sensorData.light2) + "," + 
                 String(sensorData.temperature, 2);
    bleuart.println(data);
    Serial.println(data);
}

void sendHeartRateData() {
    String data = "H," + String(sensorData.heartRate);
    bleuart.println(data);
    Serial.println(data);
}

void sendMotionData() {

  // NOTE: if you are working on the code for something else other than motion then maybe just comment this out
  //        the constant stream of accelerometer data gets nauseating.
  
    String data = "M," + 
                 String(sensorData.mpu.accelX) + "," +
                 String(sensorData.mpu.accelY) + "," +
                 String(sensorData.mpu.accelZ) + "," +
                 String(sensorData.mpu.gyroX) + "," +
                 String(sensorData.mpu.gyroY) + "," +
                 String(sensorData.mpu.gyroZ) + "," +
                 String(sensorData.mpu.pitch, 2) + "," +
                 String(sensorData.mpu.roll, 2) + "," +
                 String(sensorData.mpu.motionIntensity, 2);
    
    bleuart.println(data);
    Serial.println(data);
  
}

// this should update the battery monitoring 
// TODO: Still need to verify this implementation of the battery
void checkBattery() {
    // Read battery voltage using Feather's built-in monitoring
    float measuredvbat = analogRead(A7);
    measuredvbat *= 2;    // Voltage divider
    measuredvbat *= 3.3;  // Reference voltage
    measuredvbat /= 1024; // 10-bit ADC resolution
    
    sensorData.batteryVoltage = measuredvbat;
    
    float batteryRange = 4.25 - 2.75;
    float voltageOffset = measuredvbat - 2.75;
    sensorData.batteryPercent = (voltageOffset / batteryRange) * 100.0;
    sensorData.batteryPercent = constrain(sensorData.batteryPercent, 0, 100);
    
    sensorData.isCharging = (measuredvbat > 4.25);
    
    // Update BLE battery service
    blebas.write(sensorData.batteryPercent);
}

// TODO: will need to test the battery
void sendBatteryData() {
    String data = "B," + 
                 String(sensorData.batteryVoltage, 2) + "," +
                 String(sensorData.batteryPercent) + "," +
                 String(sensorData.isCharging ? 1 : 0);
    
    bleuart.println(data);
    Serial.println(data);
}

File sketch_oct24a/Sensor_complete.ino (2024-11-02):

#include <SoftwareSerial.h>
#include <Wire.h>

// Pin definitions for Adafruit Feather nRF52840
#define LIGHT_SENSOR_1_PIN A0  // Use A0 (P0.26)
#define LIGHT_SENSOR_2_PIN A1  // Use A1 (P0.27)
#define TEMP_SENSOR_PIN A2     // Use A2 (P0.28)
#define HEART_RATE_PIN A3      // Use A3 (P0.29)

// Bluetooth module pins (if using SoftSerial)
#define BT_RX 2  // Use GPIO2 (P0.02)
#define BT_TX 3  // Use GPIO3 (P0.03)

// Battery monitoring stuff
#define BATTERY_PIN A7      // feather's battery pin
#define VBAT_DIVIDER 2      // the nRF52840's built-in voltage divider
#define VBAT_MAX 4.25       // max voltage for 472228 battery
#define VBAT_MIN 2.75       // min voltage for 472228 battery

#define MC3419_ADDR 0x4C    // I2C address

// MC3419 Registers
#define REG_MODE 0x07       // Mode control
#define REG_SR 0x08         // Sample rate
#define REG_RANGE 0x20      // Range control
#define REG_XOUT_LSB 0x0D   // Data registers
#define REG_XOUT_MSB 0x0E
#define REG_YOUT_LSB 0x0F
#define REG_YOUT_MSB 0x10
#define REG_ZOUT_LSB 0x11
#define REG_ZOUT_MSB 0x12

// MC3419 settings
#define MODE_STANDBY 0x00
#define MODE_WAKE 0x01
#define SR_125HZ 0x03       // 125Hz output rate
#define RANGE_2G 0x00       // ±2g range

// Create Bluetooth serial connection
SoftwareSerial bluetooth(BT_RX, BT_TX);

// Timing variables (all in milliseconds)
const unsigned long LIGHT_TEMP_INTERVAL = 300000;  // 5 minutes
const unsigned long HEART_RATE_INTERVAL = 120000;  // 2 minutes
const unsigned long ACCEL_INTERVAL = 100;          // 100ms (10Hz)
const unsigned long BATTERY_INTERVAL = 1000;       // 1 second

unsigned long lastLightTempReading = 0;
unsigned long lastHeartRateReading = 0;
unsigned long lastAccelReading = 0;
unsigned long lastBatteryReading = 0;

// Sensor state management
enum SensorState {
    LIGHT_TEMP,
    HEART_RATE,
    ACCELEROMETER,
    BATTERY_CHECK,
    IDLE
};

SensorState currentState = IDLE;

// Buffer for sensor readings
struct SensorData {
    int light1;
    int light2;
    float temperature;
    int heartRate;
    int16_t accelRawX;
    int16_t accelRawY;
    int16_t accelRawZ;
    float accelG_X;
    float accelG_Y;
    float accelG_Z;
    float motionIntensity;
    float batteryVoltage;
    int batteryPercent;
    bool isCharging;
} sensorData;

const int SAMPLES = 100;
int ppgBuffer[SAMPLES];
int bufferIndex = 0;

// Heart rate detection variables
float threshold = 0.5;  // Threshold for peak detection
int peakCount = 0;
unsigned long lastPeakTime = 0;
float accelSensitivity = 16384.0f;  // LSB/g for ±2g range
bool accelInitialized = false;

// Write helper for the MC3419
void writeAccelRegister(uint8_t reg, uint8_t value) {
    Wire.beginTransmission(MC3419_ADDR);
    Wire.write(reg);
    Wire.write(value);
    Wire.endTransmission();
}

// Read accelerometer
void readAccelerometer() {
    if (!accelInitialized) return;

    Wire.beginTransmission(MC3419_ADDR);
    Wire.write(REG_XOUT_LSB);
    Wire.endTransmission(false);
    Wire.requestFrom(MC3419_ADDR, 6);

    if (Wire.available() >= 6) {
        uint8_t xL = Wire.read();
        uint8_t xH = Wire.read();
        uint8_t yL = Wire.read();
        uint8_t yH = Wire.read();
        uint8_t zL = Wire.read();
        uint8_t zH = Wire.read();

        sensorData.accelRawX = (xH << 8) | xL;
        sensorData.accelRawY = (yH << 8) | yL;
        sensorData.accelRawZ = (zH << 8) | zL;

        // Converting to g (16384 LSB/g for ±2g range)
        sensorData.accelG_X = sensorData.accelRawX / 16384.0;
        sensorData.accelG_Y = sensorData.accelRawY / 16384.0;
        sensorData.accelG_Z = sensorData.accelRawZ / 16384.0;

        sensorData.motionIntensity = sqrt(
            sensorData.accelG_X * sensorData.accelG_X +
            sensorData.accelG_Y * sensorData.accelG_Y +
            sensorData.accelG_Z * sensorData.accelG_Z
        );
    }
}

bool initializeMC3419() {
    Wire.begin();

    // Initialization sequence
    writeAccelRegister(REG_MODE, MODE_STANDBY);
    delay(10);

    writeAccelRegister(REG_RANGE, RANGE_2G);
    writeAccelRegister(REG_SR, SR_125HZ);

    writeAccelRegister(REG_MODE, MODE_WAKE);
    delay(3);

    return true;
}

void setup() {
    // Initialize serial communications
    Serial.begin(9600);
    bluetooth.begin(9600);

    // Initialize analog pins
    pinMode(LIGHT_SENSOR_1_PIN, INPUT);
    pinMode(LIGHT_SENSOR_2_PIN, INPUT);
    pinMode(TEMP_SENSOR_PIN, INPUT);
    pinMode(HEART_RATE_PIN, INPUT);

    // Initializing the accelerometer
    accelInitialized = initializeMC3419();
    if (!accelInitialized) {
        Serial.println("Could not initialize MC3419!");
    }
}

void loop() {
    unsigned long currentTime = millis();

    // Check if it's time to read light and temperature sensors
    if (currentTime - lastLightTempReading >= LIGHT_TEMP_INTERVAL) {
        currentState = LIGHT_TEMP;
        lastLightTempReading = currentTime;
    }

    // Check if it's time to read heart rate sensor
    if (currentTime - lastHeartRateReading >= HEART_RATE_INTERVAL) {
        currentState = HEART_RATE;
        lastHeartRateReading = currentTime;
    }

    // Check if it's time to read accelerometer
    if (currentTime - lastAccelReading >= ACCEL_INTERVAL) {
        currentState = ACCELEROMETER;
        lastAccelReading = currentTime;
    }

    // Check if it's time to check the battery
    if (currentTime - lastBatteryReading >= BATTERY_INTERVAL) {
        currentState = BATTERY_CHECK;
        lastBatteryReading = currentTime;
    }

    // Process the current state
    processCurrentState();

    // Small delay to prevent overwhelming the system
    delay(10);
}

void processCurrentState() {
    switch (currentState) {
        case LIGHT_TEMP:
            sensorData.light1 = analogRead(LIGHT_SENSOR_1_PIN);
            sensorData.light2 = analogRead(LIGHT_SENSOR_2_PIN);

            // Convert analog reading to temperature in Celsius
            int tempReading = analogRead(TEMP_SENSOR_PIN);
            float voltage = tempReading * (5.0 / 1024.0);
            sensorData.temperature = (voltage - 0.5) * 100;

            sendEnvironmentalData();
            currentState = IDLE;
            break;

        case HEART_RATE:
            sensorData.heartRate = readHeartRateSensor(HEART_RATE_PIN);
            sendHeartRateData();
            currentState = IDLE;
            break;

        case ACCELEROMETER:
            readAccelerometer();
            sendAccelData();
            currentState = IDLE;
            break;

        case BATTERY_CHECK:
            checkBattery();
            sendBatteryData();
            currentState = IDLE;
            break;

        case IDLE:
            // Do nothing in idle state
            break;
    }
}
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

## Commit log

2024-10-25 created files
    [pcb.kicad_pcb, pcb.kicad_sch]
2024-11-01 battery and acceleration
2024-11-02 pcb update
    [pcb.kicad_sch]
2024-11-07 place sensor file in separate folder + fix case statements
    [Sensor_complete.ino]
2024-11-09 Update and rename Sensor_complete.ino to Sensor_Light&Temp&Heart.ino
2024-11-12 pcb sketch updates
    [Adafruit nRF52840 Bluefruit Feather Express Rev D.kicad_sch, pcb.kicad_pcb, pcb.kicad_sch]
2024-11-13 working code for the accelerometer
2024-11-14 testing battery
2024-11-14 pcb updates
    [pcb.csv, pcb.kicad_pcb]
2024-12-04 add the latest sensor_complete code
2024-12-04 rename sensor file and add 1 second version
2024-12-04 fixed formatting of the data again to remove words and duplicate reporting
    [Sensor_Demo_Day.ino]
2024-12-04 manual delete 4
    [Adafruit nRF52840 Bluefruit Feather Express Rev D.kicad_sch]
2024-12-05 adding reset to demo day to debug
    [Sensor_Demo_Day.ino]
2024-12-05 remove reset, it doesnt work
    [Sensor_Demo_Day.ino]
2024-12-08 changed bluetooth streaming
    bluetooth now sends each sensor data in its own packet one at a time, they are sent in json format
2024-12-17 adc testing
